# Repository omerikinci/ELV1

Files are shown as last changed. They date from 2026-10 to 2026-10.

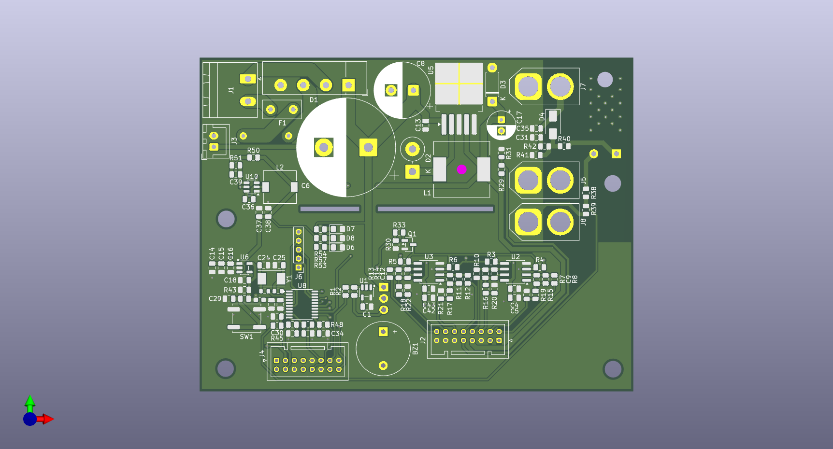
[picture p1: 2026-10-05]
hardware/Electronic Load no component.png

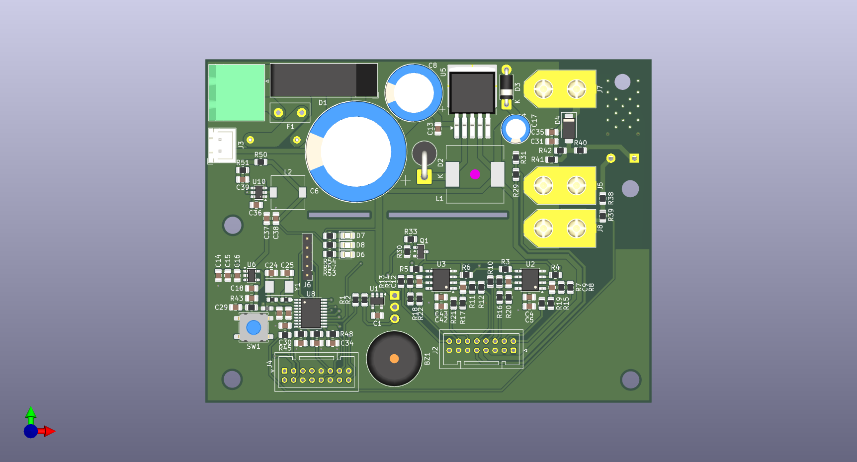
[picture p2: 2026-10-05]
hardware/Electronic Load.png

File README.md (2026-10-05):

# ELV1 — Elektronik Kör Yük V1

Elektronik kör yük (electronic dummy load) cihazının ilk stabil versiyonu.
150 W ile sınırlandırılmış, 30 V / 10 A aralığını destekler.

Proje detayları ve görseller: https://omerikinci.com/projects/electronic-dummy-load

## İçerik

| Klasör | Açıklama |
| --- | --- |
| `firmware/` | STM32G030F6 için STM32CubeIDE projesi (`ilkdeneme`). Final kod: `firmware/Core/Src/main.c` |
| `firmware-history/2026-04-27-stable/` | 27.04.2026 tarihli önceki stabil `main.c` |
| `hardware/` | KiCad şema ve PCB (`Electronic Load`), PCB görselleri, özel sembol kütüphanesi |
| `arduino-prototype/` | STM32'ye geçmeden önceki Arduino tabanlı ilk prototip (`koryukprojesi.ino`) |

## Firmware

- MCU: STM32G030F6Px
- ADS1115 (I2C) ile akım/gerilim ölçümü, dahili ADC
- DS18B20 sıcaklık sensörü
- I2C LCD, buzzer, soft-start

Derlemek için `firmware/` klasörünü STM32CubeIDE'ye mevcut proje olarak içe aktarın.

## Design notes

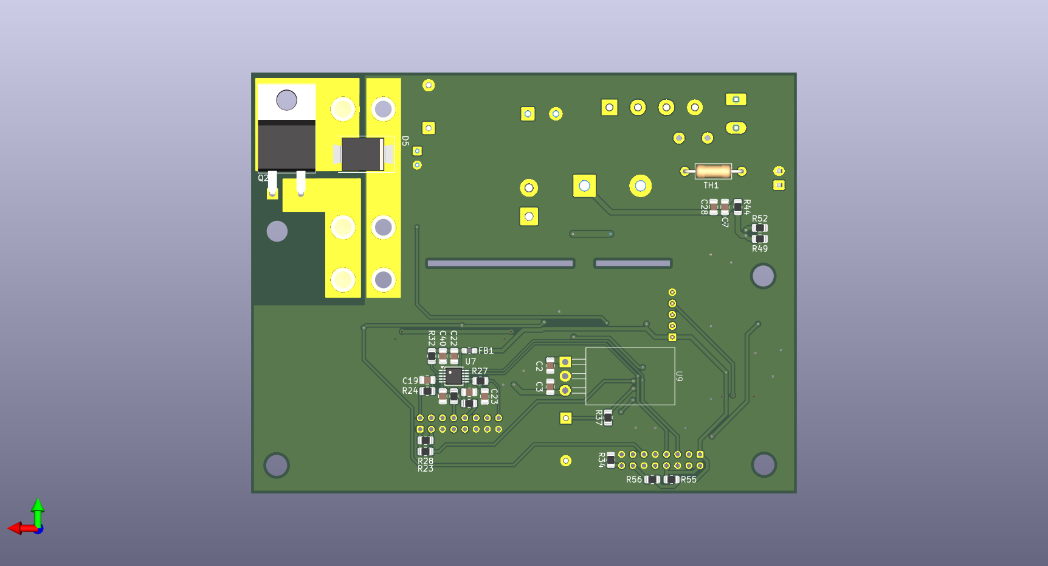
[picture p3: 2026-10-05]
hardware/Electronic Load back.png

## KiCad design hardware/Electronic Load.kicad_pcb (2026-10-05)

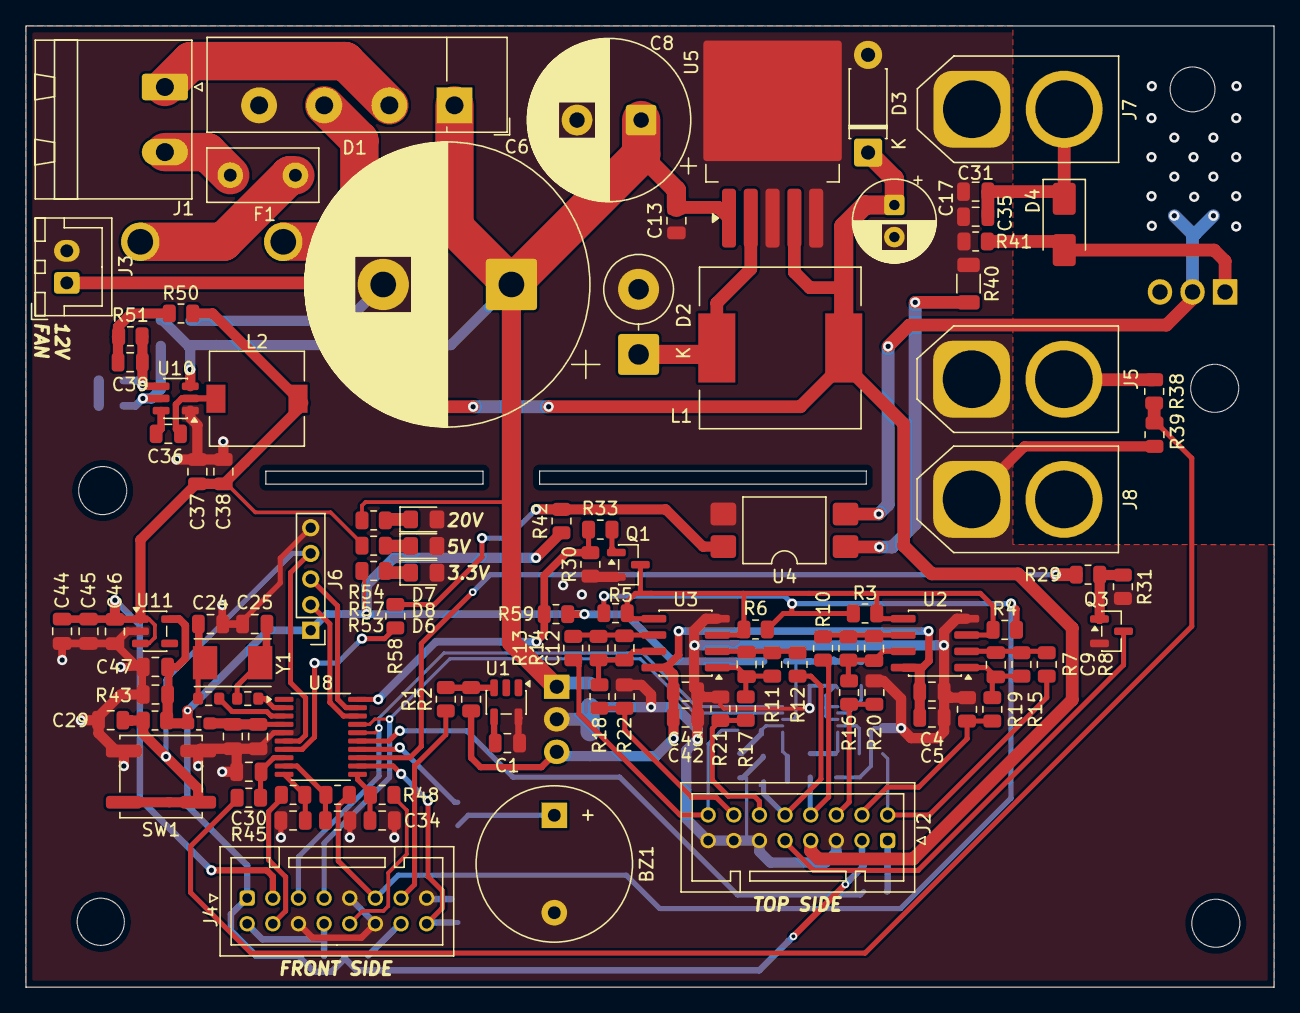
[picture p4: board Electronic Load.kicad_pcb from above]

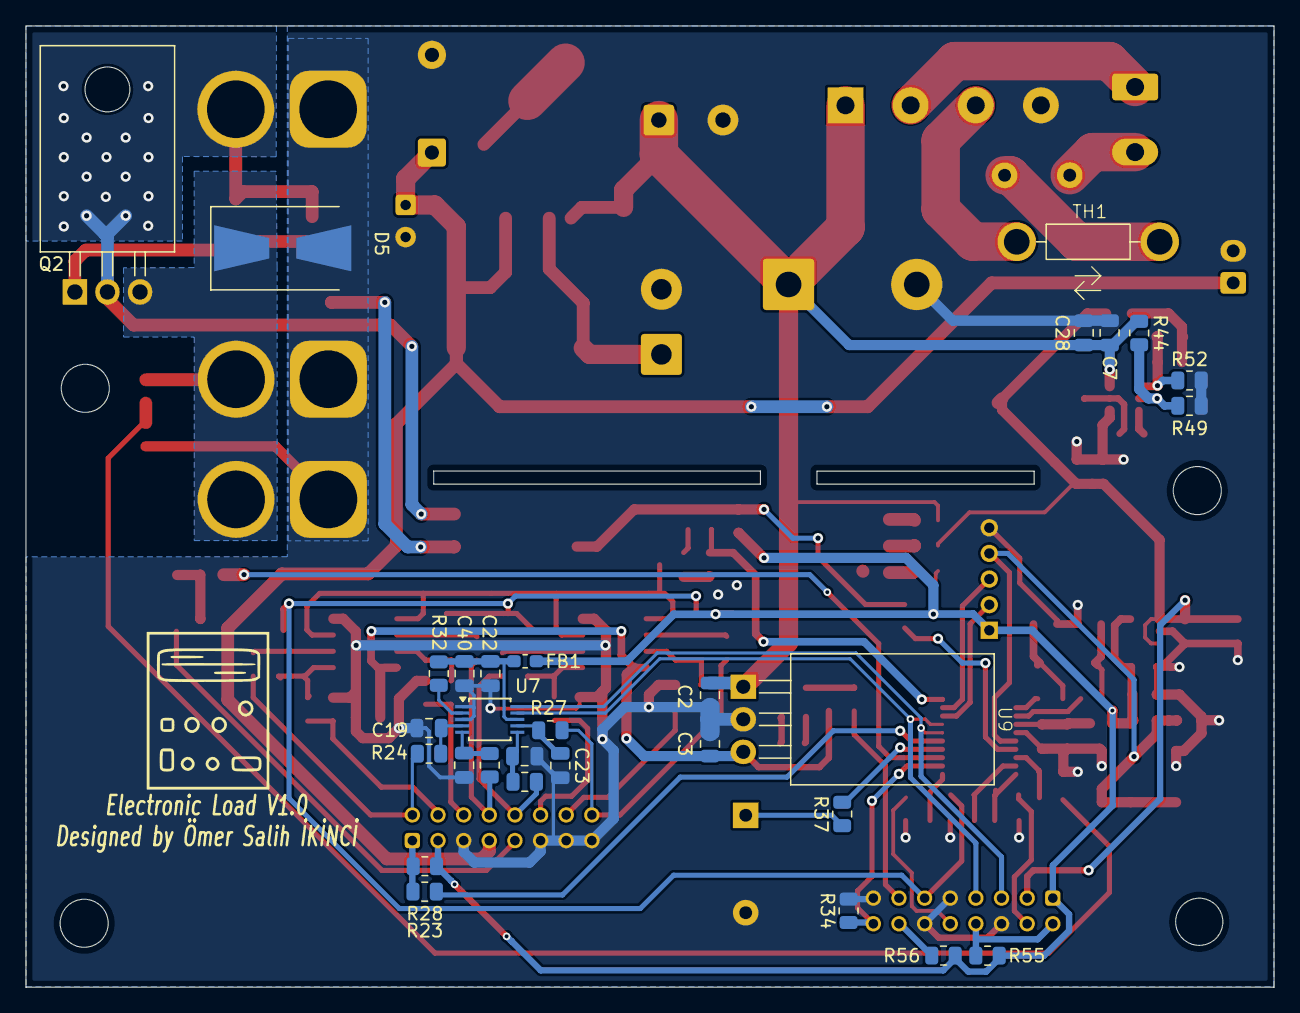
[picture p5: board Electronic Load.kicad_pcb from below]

Board: 2 copper layers, 97.3 x 75.0 mm, 140 parts (30 on the bottom side), 81 nets.

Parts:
BZ1: Buzzer; Buzzer_12x9.5RM7.6
C1, C26, C28, C40, C44: 10uF X7R; C_0805_2012Metric
C2, C3, C5, C7, C13, C19, C20, C21, C22, C23, C27, C29, C30, C32, C33, C34, C36, C42, C45, C48: 100nF X7R; C_0805_2012Metric
C4, C31, C43, C46, C47: 1uF X7R; C_0805_2012Metric
C6: 6800uF; CP_Radial_D22.0mm_P10.00mm_SnapIn
C8: 680uF 50V; CP_Radial_D12.5mm_P5.00mm
C9, C10, C11, C12: 1nF; C_0805_2012Metric
C17: 220uF 25V; CP_Radial_D6.3mm_P2.50mm
C24, C25: 18pF; C_0805_2012Metric
C35: 100nF 63V; C_0805_2012Metric
C37, C38: 22uF; C_0805_2012Metric
C39: 75pF; C_0805_2012Metric
D1: KBU8M; Diode_Bridge_Vishay_KBU
D2: 1N5822; D_DO-201AD_P5.08mm_Vertical_KathodeUp
D3: 1N4007; D_DO-41_SOD81_P7.62mm_Horizontal
D4: 12V ZENER; D_SMA
D5: SMCJ33CA-TKS; D_SMB-SMC_Universal_Handsoldering
D6, D7, D8: RED LED; LED_0805_2012Metric_Pad1.15x1.40mm_HandSolder
F1: 2A Slow Blow; Fuse_Littelfuse_395Series
FB1, FB2: 600R 100MHz; L_0603_1608Metric_Pad1.05x0.95mm_HandSolder
J1: 15VAC Transformer out; PhoenixContact_MSTBA_2,5_2-G-5,08_1x02_P5.08mm_Horizontal
J2: Top Panel; JST_PUD_B16B-PUDSS_2x08_P2.00mm_Vertical
J3: FAN OUT; JST_XH_B2B-XH-A_1x02_P2.50mm_Vertical
J4: Front Panel; JST_PUD_B16B-PUDSS_2x08_P2.00mm_Vertical
J5: power in (inside); AMASS_XT60-M_1x02_P7.20mm_Vertical
J6: Program Pins; PinHeader_1x05_P2.00mm_Vertical
J7: power in (outside); AMASS_XT60-M_1x02_P7.20mm_Vertical
J8: power in (outside) for batteries; AMASS_XT60-M_1x02_P7.20mm_Vertical
L1: 33uH; L_12x12mm_H8mm
L2: 10uH; L_7.3x7.3_H4.5
Q1, Q3: IRLML6344TRPBF; SOT-23
Q2: IRF4905; TO-220F-3_Horizontal_TabDown
R1: 22K; R_0805_2012Metric
R2, R19, R20, R21, R22, R30, R31, R32, R34, R42, R43, R59: 10K; R_0805_2012Metric
R3, R4, R5, R6, R8, R10, R12, R14, R24, R25, R26, R27, R41, R45, R46, R47, R48, R54, R55, R56: 1K; R_0805_2012Metric
R7, R9, R11, R13: 220K; R_0805_2012Metric
R15, R16, R17, R18, R23, R33, R37, R57: 100R; R_0805_2012Metric
R28: 4.7K; R_0805_2012Metric
R29, R58: 100; R_0805_2012Metric
R35, R36: 0R; R_0603_1608Metric
R38: 470K; R_0805_2012Metric
R39: 33K; R_0805_2012Metric
R40: 5.6K; R_1206_3216Metric
R44: 511K; R_0805_2012Metric
R49: 105K; R_0805_2012Metric
R50: 49.9R; R_0805_2012Metric
R51: 100K; R_0805_2012Metric
R52: 13.3K; R_0805_2012Metric
R53: 10R; R_0805_2012Metric
SW1: SW_Push_1P1T_NO_CK_KSC7xxJ
TH1: NTC 10R; Untitled
U1: TL431DBV; SOT-23-5
U2, U3: LM358; SOIC-8_3.9x4.9mm_P1.27mm
U4: LTV-817S; SMDIP-4_W9.53mm
U5: LM2596S-12; TO-263-5_TabPin3
U7: ADS1115IDGS; TSSOP-10_3x3mm_P0.5mm
U8: STM32G030F6Px; TSSOP-20_4.4x6.5mm_P0.65mm
U9: LM7815_TO220; myto220
U10: TPS54302; SOT-23-6
U11: AP2112K-3.3; SOT-23-5
Y1: 8mHz; Crystal_SMD_Abracon_ABM7-2Pin_6.0x3.5mm

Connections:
/3.3V: C47.1, C48.1, FB1.1, FB2.1, J2.3, J4.1, J6.1, R28.1, R42.2, R43.2, R53.2, R55.1, R56.1, R59.1, U11.5 (VOUT)
/5V: C37.1, C38.1, C44.1, C45.1, C46.1, J4.3, L2.2, R50.1, R57.2, U11.1 (VIN), U11.3 (EN)
/20V: C2.1, C6.1, C7.1, C8.1, C13.1, C28.1, D1.1 (+), R44.1, R54.2, U5.1 (VIN), U9.1 (VI), U10.3 (VIN)
/A POT SIGNAL: J4.11, R3.2, R4.2, R5.2, R6.2, R46.2
/A POT VCC: J4.13, R1.1
/ADS1115/SCREEN SCL: J4.5, U7.10 (SCL), U8.16 (PA9/PA11)
/ADS1115/SCREEN SDA: J4.7, U7.9 (SDA), U8.17 (PA10/PA12)
/AR0: J2.2, R8.1, R24.2
/AR1: J2.8, R10.1, R25.2
/AR2: J2.10, R12.1, R26.2
/AR3: J2.16, R14.1, R27.2
/BUZZER: R37.2, U8.14 (PA7)
/DRAIN SIDE: C31.1, C35.1, D4.1 (K), J7.2, Q2.2 (D), U4.2
/DS18B20 DQ: R23.2, U8.15 (PA8/PB0/PB1/PB2)
/FAN CONTROL: R29.2, U8.13 (PA6)
/FAN SIGNAL: J2.9, Q3.3 (D)
/FAN VCC: C17.1, D3.1 (K), J2.7, J3.1, L1.2, U5.4 (FB)
/G1: J2.4, R15.1, R19.1
/G2: J2.6, R16.1, R20.1
/G3: J2.12, R17.1, R21.1
/G4: J2.14, R18.1, R22.1
/LOAD VOLTAGE: R38.1, R39.2, R45.2
/OCS: Q1.3 (D), R3.1, R4.1, R5.1, R6.1, U2.3 (+), U2.5 (+), U3.3 (+), U3.5 (+)
/OPAMP CONTROL: R30.1, R33.1, R59.2, U8.20 (PB3/PB4/PB5/PB6)
/Opamp VCC: C3.1, C4.1, C5.1, C42.1, C43.1, R2.1, U2.8 (V+), U3.8 (V+), U9.3 (VO)
/RCP: R58.2, U8.7 (PA0)
/RESET BUTTON: J4.16, R34.1, U8.12 (PA5)
/SET C POT: J4.10, R48.2
/SET V POT: J4.4, R47.2
/SOURCE SIDE: D5.1 (A1), J5.2, J8.2, Q2.3 (S), R38.2
GND: BZ1.2 (-), C1.2, C2.2, C3.2, C4.2, C5.2, C6.2, C7.2, C8.2, C13.2, C17.2, C19.2, C20.2, C21.2, C22.2, C23.2, C24.1, C25.1, C26.2, C27.2, C28.2, C29.2, C30.2, C31.2, C32.2, C33.2, C34.2, C35.2, C37.2, C38.2, C40.2, C42.2, C43.2, C44.2, C45.2, C46.2, C47.2, C48.2, D1.4 (-), D2.2 (A), D3.2 (A), D5.2 (A2), D6.2 (A), D7.2 (A), D8.2 (A), J2.5, J2.11, J2.13, J2.15, J3.2, J4.6, J4.9, J4.12, J4.15, J5.1, J6.5, J7.1, J8.1, Q1.2 (S), Q3.2 (S), R19.2, R20.2, R21.2, R22.2, R30.2, R31.1, R34.2, R39.1, R40.1, R41.1, R49.2, R52.2, SW1.2, U1.5 (A), U2.4 (V-), U3.4 (V-), U4.3, U5.3 (GND), U5.5 (~ON/OFF), U7.1 (ADDR), U7.3 (GND), U8.5 (VSS), U9.2 (GND), U10.1 (GND), U11.2 (GND)
unnamed: BZ1.1 (+), R37.1
unnamed: C9.2, R7.1, R15.2, U2.1
unnamed: C10.2, R9.1, R16.2, U2.7
unnamed: C11.2, R11.1, R17.2, U3.1
unnamed: C12.2, R13.1, R18.2, U3.7
unnamed: C24.2, R35.1, Y1.2
unnamed: C25.2, R36.1, Y1.1
unnamed: C39.1, R50.2, R51.1
unnamed: D1.3, TH1.1
unnamed: D2.1 (K), L1.1, U5.2 (OUT)
unnamed: D4.2 (A), Q2.1 (G), R41.2
unnamed: D6.1 (K), R53.1
unnamed: D7.1 (K), R54.1
unnamed: D8.1 (K), R57.1
unnamed: F1.2, TH1.2
unnamed: D1.2, J1.1
unnamed: F1.1, J1.2
unnamed: J2.1, R23.1, R28.2
unnamed: J4.2, J4.8, R55.2
unnamed: J4.14, R56.2
unnamed: J6.2, U8.18 (PA13)
unnamed: J6.3, U8.19 (PA14/PA15)
unnamed: C29.1, J6.4, R43.1, SW1.1, U8.6 (NRST)
unnamed: Q1.1 (G), R33.2
unnamed: Q3.1 (G), R29.1, R31.2
unnamed: R40.2, U4.1
unnamed: R42.1, R58.1, U4.4
unnamed: R1.2, R2.2, U1.3 (K)
unnamed: C1.1, U1.4 (REF)
unnamed: C9.1, R7.2, R8.2, U2.2 (-)
unnamed: C10.1, R9.2, R10.2, U2.6 (-)
unnamed: C11.1, R11.2, R12.2, U3.2 (-)
unnamed: C12.1, R13.2, R14.2, U3.6 (-)
unnamed: C19.1, R24.1, U7.4 (AIN0)
unnamed: C20.1, R25.1, U7.5 (AIN1)
unnamed: C21.1, R26.1, U7.6 (AIN2)
unnamed: C23.1, R27.1, U7.7 (AIN3)
unnamed: R32.1, U7.2 (ALERT/RDY)
unnamed: C22.1, C40.1, FB1.2, R32.2, U7.8 (VDD)
unnamed: C30.1, R45.1, U8.8 (PA1)
unnamed: C32.1, R46.1, U8.9 (PA2)
unnamed: C33.1, R47.1, U8.10 (PA3)
unnamed: C34.1, R48.1, U8.11 (PA4)
unnamed: R36.2, U8.2 (PB9/PC14)
unnamed: R35.2, U8.3 (PC15)
unnamed: C26.1, C27.1, FB2.2, U8.4 (VDD)
unnamed: C36.1, U10.6 (BOOT)
unnamed: R44.2, R49.1, U10.5 (EN)
unnamed: C39.2, R51.2, R52.1, U10.4 (FB)
unnamed: C36.2, L2.1, U10.2 (SW)

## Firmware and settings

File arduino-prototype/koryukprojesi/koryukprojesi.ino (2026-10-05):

/*
 * Arduino Electronic Load Project (FINAL VERSION - 20x4 EDITION)
 * -----------------------------------------------------------
 * - OPTIMIZED FOR 20x4 DISPLAY (Professional Look) -
 * - ENGLISH INTERFACE FOR YOUTUBE / GLOBAL USE -
 * - HIGH VOLTAGE PROTECTION & MAX 20V SET LIMIT -
 * - FIXED: Display Flickering (Titreme) and Overwrite Issues -
 * - PREMIUM FEATURES: Fan Animation, Progress Bar, Haptic Sound -
 * -----------------------------------------------------------
 * * * PIN CONNECTIONS:
 * A0: Current Sense (1V = 1A)
 * A1: Voltage Sense (Max 50V)
 * A2: Set Current Pot (Max 5A)
 * A3: Set Voltage Pot (Max 20V)
 * D8: Load Control MOSFET (Safety Cutoff - HIGH triggers OFF)
 * D2: Reset Button (Active LOW)
 * D5: Buzzer
 * D9: DS18B20 One-Wire Bus
 * D11: Fan MOSFET (Low-Side Switching)
 * SDA/SCL: 20x4 I2C LCD Display
 */

#include <Wire.h>
#include <LiquidCrystal_I2C.h>
#include <OneWire.h>
#include <DallasTemperature.h>

// --- LCD Settings (UPDATED FOR 20x4) ---
LiquidCrystal_I2C lcd(0x27, 20, 4);  // 20 Columns, 4 Rows

// --- Pin Definitions ---
const int CURRENT_PIN = A0;
const int VOLTAGE_PIN = A1;
const int SET_CURRENT_PIN = A2;
const int SET_VOLTAGE_PIN = A3;
const int INDICATOR_POT_PIN = A7;

const int RESET_BUTTON_PIN = 2;
const int BUZZER_PIN = 5;
const int LOAD_CONTROL_PIN = 8;    // D8 - Safety Cutoff MOSFET
const int ONE_WIRE_BUS_PIN = 9;    // D9 - DS18B20 Sensors
const int FAN_MOSFET_PIN = 11;     // D11 - Fan MOSFET

// --- Control Logic ---
const int LOAD_ON = LOW;       // Normal Operation (D8 LOW)
const int LOAD_OFF = HIGH;     // Fault State (D8 HIGH)
const int FAN_ON = HIGH;
const int FAN_OFF = LOW;

// --- Calibration & Settings ---
const float V_REF = 5.0;  
const float VOLTAGE_DIVIDER_RATIO = 11.0;  
const float MIN_CURRENT_THRESHOLD = 0.05;  

// --- Thermal Control Settings ---
const float FAN_ON_TEMP_THRESHOLD = 55.0;
const float FAN_OFF_TEMP_THRESHOLD = 45.0;
const float TEMP_FAULT_LIMIT = 65.0;  

// --- PROTECTION LIMITS ---
const float HIGH_VOLTAGE_PROTECTION = 21.0;  

// --- Global Variables ---
float actualVoltage = 0.0;
float actualCurrent = 0.0;
float setVoltage = 0.0;
float setCurrent = 0.0;
float power = 0.0;
int indicatorPotValue = 0;

bool faultState = false;
String faultMessage = "";

// --- Temp & Fan Variables ---
OneWire oneWire(ONE_WIRE_BUS_PIN);
DallasTemperature sensors(&oneWire);
float tempS2 = 0.0; // S2 (MOSFET Temp)
float tempS1 = 0.0; // S1 (Resistor Temp)
bool isFanOn = false;

// Sabit etiketleri sadece bir kez yazdırmak için bayraklar
bool labelsPrinted = false;

// --- Timing Variables for Async Temp Reading ---
unsigned long lastTempUpdate = 0;
const unsigned long TEMP_UPDATE_INTERVAL = 1000; // 1 saniyede bir sıcaklık oku

// --- Custom Characters & Animation ---
byte charFan1[8] = {0x04,0x0E,0x1F,0x04,0x1F,0x0E,0x04,0x00}; // Pervane +
byte charFan2[8] = {0x1B,0x0E,0x04,0x0E,0x1B,0x00,0x00,0x00}; // Pervane x
byte charBar[8]  = {0xFF,0xFF,0xFF,0xFF,0xFF,0xFF,0xFF,0xFF}; // Full Block

unsigned long lastFanAnimTime = 0;
const int FAN_ANIM_DELAY = 250; // 250ms de bir yön değişir
int fanFrame = 0; // 0 veya 1


void setup() {
  Serial.begin(9600);

  // Set Pin Modes
  pinMode(LOAD_CONTROL_PIN, OUTPUT);
  pinMode(RESET_BUTTON_PIN, INPUT);
  pinMode(BUZZER_PIN, OUTPUT);
  pinMode(FAN_MOSFET_PIN, OUTPUT);
  
  // Initial States
  digitalWrite(LOAD_CONTROL_PIN, LOAD_ON);    // Load ON
  digitalWrite(BUZZER_PIN, LOW);             // Buzzer OFF
  digitalWrite(FAN_MOSFET_PIN, FAN_OFF);     // Fan OFF
  
  // Init LCD
  lcd.init();
  lcd.backlight();
  lcd.clear();
  
  // Create Custom Characters
  lcd.createChar(0, charFan1);
  lcd.createChar(1, charFan2);
  lcd.createChar(2, charBar); // Progress Bar Block

  // --- SHOW LOADING SCREEN ---
  lcd.setCursor(2, 1);
  lcd.print("SYSTEM STARTING");
  
  // Progress Bar Animation (20 Karakterlik Çubuk)
  lcd.setCursor(0, 2);
  for (int i = 0; i < 20; i++) {
    lcd.write(2); // Block karakterini yaz
    delay(75);    // Hız ayarı (Toplam ~1.5sn sürer)
  }
  
  lcd.clear();
  
  // --- WELCOME SCREEN (Short) ---
  lcd.setCursor(2, 0);  
  lcd.print("ELECTRONIC LOAD");
  lcd.setCursor(4, 1);
  lcd.print("Version 2.0"); // V2.0 PRO
  delay(1500);
  
  // Init Sensors
  sensors.begin();
  
  // ASYNC MODE: İşlemciyi bekletme
  sensors.setWaitForConversion(false); 
  sensors.requestTemperatures(); // İlk çevrimi başlat
  
  delay(100); 

  faultState = false;
  lcd.clear();
  // İlk çalıştırmada sabit etiketleri yazdır
  printFixedLabels(); 
}

/**
 * @brief Ekrana sabit etiketleri (Set:, Act:, Pwr:, Mos:, Res:, Pot:) sadece bir kez yazar.
 * Bu, ana döngüde (loop) tekrarlanan yazımı ve titremeyi önler.
 */
void printFixedLabels() {
  // Line 1: Set Values Labels
  lcd.setCursor(0, 0);
  lcd.print("Set: ");
  // Line 2: Actual Values Labels
  lcd.setCursor(0, 1);
  lcd.print("Act: ");
  // Line 3: Power & Pot Labels
  lcd.setCursor(0, 2);
  lcd.print("Pwr: "); // POWER -> PWR KISALTILDI
  lcd.setCursor(11, 2); // POT Sola hizalandı
  lcd.print("Pot:"); 
  // Line 4: Temps Labels
  lcd.setCursor(0, 3);
  lcd.print("Mos:");
  lcd.setCursor(8, 3); // Res Sola hizalandı
  lcd.print("Res:");
  
  labelsPrinted = true;
}


void loop() {
  
  // 1. Check Reset Button
  if (faultState == true) {
    if (digitalRead(RESET_BUTTON_PIN) == LOW) {  
      delay(50); // Debounce
      if (digitalRead(RESET_BUTTON_PIN) == LOW) {
        // Reset Faults
        tone(BUZZER_PIN, 2000, 100); // Bip sesi ile onay
        faultState = false;
        faultMessage = "";
        digitalWrite(LOAD_CONTROL_PIN, LOAD_ON);  
        digitalWrite(BUZZER_PIN, LOW);            
        lcd.clear();
        lcd.setCursor(3, 1);
        lcd.print("SYSTEM ACTIVE");
        delay(1000);
        lcd.clear();
        // Reset sonrası sabit etiketleri yeniden yazdır
        printFixedLabels(); 
        return;
      }
    }
  }

  // 2. Read Sensors
  readSensors();
  readTemperatures();

  // 3. Fan Control
  controlFan();

  // 4. Fault Check
  if (faultState == false) {
    
    // *** HIGH VOLTAGE PROTECTION (>21V) ***
    if (actualVoltage > HIGH_VOLTAGE_PROTECTION) {  
      setFault("FAULT: HIGH VOLTAGE");
    }
    // Over Current
    else if (actualCurrent > setCurrent) {
      setFault("FAULT: OVER CURRENT");
    }  
    // Low Voltage
    else if (actualVoltage < setVoltage && actualCurrent > MIN_CURRENT_THRESHOLD) {
      setFault("FAULT: LOW VOLTAGE");
    }
    // Over Temp
    else if (tempS1 > TEMP_FAULT_LIMIT || tempS2 > TEMP_FAULT_LIMIT) {
      setFault("FAULT: OVER HEATING");
    }
  }

  // 5. Update Display
  if (faultState) {
    displayFault();
  } else {
    // Sabit etiketler (Set:, Act:, Pwr: vb.) zaten yazıldıysa, sadece dinamik değerleri güncelle
    updateDynamicValues();
  }
}

/**
 * @brief Triggers a system fault.
 */
void setFault(String message) {
  faultState = true;
  faultMessage = message;
  
  digitalWrite(LOAD_CONTROL_PIN, LOAD_OFF); // Cut Power
  digitalWrite(BUZZER_PIN, HIGH);
  lcd.clear(); // Hata durumunda ekranı temizle (Mos vb. kalmasın)
}

/**
 * @brief Reads all analog inputs.
 */
void readSensors() {
  // Set Current (Max 5A)
  int setAmperRaw = analogRead(SET_CURRENT_PIN);
  setCurrent = map(setAmperRaw, 0, 1023, 0, 500) / 100.0;

  // Set Voltage (Max 20V Limit)
  int setVoltajRaw = analogRead(SET_VOLTAGE_PIN);
  setVoltage = map(setVoltajRaw, 0, 1023, 0, 2000) / 100.0;  

  // Actual Current
  int actualCurrentRaw = analogRead(CURRENT_PIN);
  float actualCurrentVolts = (actualCurrentRaw / 1023.0) * V_REF;
  actualCurrent = actualCurrentVolts;  

  // Actual Voltage
  int actualVoltajRaw = analogRead(VOLTAGE_PIN);
  float pinVoltage = (actualVoltajRaw / 1023.0) * V_REF;
  actualVoltage = pinVoltage * VOLTAGE_DIVIDER_RATIO;
  
  power = actualVoltage * actualCurrent;
  indicatorPotValue = analogRead(INDICATOR_POT_PIN);
}

void readTemperatures() {
  // Sadece 1 saniyede bir işlem yap (Non-blocking)
  if (millis() - lastTempUpdate >= TEMP_UPDATE_INTERVAL) {
    lastTempUpdate = millis();
    
    // 1. Sensörde HAZIR olan değeri oku (Bir önceki istekten gelen)
    float temp1 = sensors.getTempCByIndex(1);
    float temp0 = sensors.getTempCByIndex(0);

    if (temp0 != DEVICE_DISCONNECTED_C && temp0 > -127.0) {
      tempS2 = temp0; // Index 0 -> S2 (Resistor)
    }
    if (temp1 != DEVICE_DISCONNECTED_C && temp1 > -127.0) {
      tempS1 = temp1; // Index 1 -> S1 (MOSFET)
    }
    
    // 2. Bir SONRAKİ okuma için sensöre "Çevrime Başla" emri ver
    // WaitForConversion(false) olduğu için işlemciyi bekletmez, hemen döner.
    sensors.requestTemperatures();
  }
}

/**
 * @brief Controls Fan based on temp.
 */
void controlFan() {
  if (tempS1 > FAN_ON_TEMP_THRESHOLD || tempS2 > FAN_ON_TEMP_THRESHOLD) {
    isFanOn = true;
  }  
  else if (tempS1 < FAN_OFF_TEMP_THRESHOLD && tempS2 < FAN_OFF_TEMP_THRESHOLD) {
    isFanOn = false;
  }
  
  if (isFanOn) {
    digitalWrite(FAN_MOSFET_PIN, FAN_ON);  
  } else {
    digitalWrite(FAN_MOSFET_PIN, FAN_OFF);  
  }
}

/**
 * @brief Sadece dinamik değerleri günceller, sabit etiketlere dokunmaz. (20x4 Optimized)
 */
void updateDynamicValues() {
  // Line 1: Set Values
  // Başlangıç: Kolon 5 (Set: 01234)
  lcd.setCursor(5, 0); 
  lcd.print(String(setVoltage, 1));
  lcd.print("V "); // Sabit uzunluk koruma (Tek boşluk)
  // Başlangıç: Kolon 11
  lcd.setCursor(11, 0); 
  lcd.print(String(setCurrent, 2));
  lcd.print("A "); // Sabit uzunluk koruma (Tek boşluk)

  // Line 2: Actual Values
  // Başlangıç: Kolon 5 (Act: 01234)
  lcd.setCursor(5, 1);
  lcd.print(String(actualVoltage, 1));
  lcd.print("V "); // Sabit uzunluk koruma
  // Başlangıç: Kolon 11
  lcd.setCursor(11, 1);
  lcd.print(String(actualCurrent, 2));
  lcd.print("A "); // Sabit uzunluk koruma

  // Line 3: Power & Pot
  // Başlangıç: Kolon 5 (Pwr: 01234)
  lcd.setCursor(5, 2);
  lcd.print(String(power, 1));
  lcd.print("W "); // Sabit uzunluk koruma - Tek boşluk (P harfini korur)
  
  // Pot değerini güncelle. Başlangıç: Kolon 15 (Pot: 12345)
  lcd.setCursor(15, 2); 
  lcd.print(indicatorPotValue);
  
  // Taşmayı önlemek için akıllı boşluk (Toplam 5 karakter alanı: 15-19)
  if (indicatorPotValue < 10) lcd.print("    ");      // 1 rakam + 4 boşluk
  else if (indicatorPotValue < 100) lcd.print("   "); // 2 rakam + 3 boşluk
  else if (indicatorPotValue < 1000) lcd.print("  "); // 3 rakam + 2 boşluk
  else lcd.print(" ");                                // 4 rakam + 1 boşluk

  // Line 4: Temps & Fan Status
  // Mos Temp. Başlangıç: Kolon 4 (Mos: 0123)
  lcd.setCursor(4, 3);
  lcd.print(String((int)tempS1)); 
  lcd.print("C "); // Sabit uzunluk koruma
  
  // Res Temp. Başlangıç: Kolon 12 (Res: 8901)
  lcd.setCursor(12, 3);
  lcd.print(String((int)tempS2));
  lcd.print("C ");
  
  // Fan Status. Başlangıç: Kolon 16
  lcd.setCursor(16, 3);
  if (isFanOn) {
    // Animasyon Mantığı
    if (millis() - lastFanAnimTime >= FAN_ANIM_DELAY) {
      lastFanAnimTime = millis();
      fanFrame = !fanFrame; // 0 -> 1, 1 -> 0 Geçiş
    }
    
    lcd.print("FAN");
    lcd.write(fanFrame); // 0 veya 1 nolu karakteri bas
  } else {
    lcd.print("    "); // Temizle
  }
}

/**
 * @brief Displays Fault Screen (Centered)
 */
void displayFault() {
  // Line 0: Header (Centered)
  // "SYSTEM HALTED!" is 14 chars. (20-14)/2 = 3
  lcd.setCursor(3, 0);
  lcd.print("SYSTEM HALTED!");

  // Line 1: Error Message (Dynamic)
  lcd.setCursor(0, 1);
  lcd.print(faultMessage); // e.g. "FAULT: HIGH VOLTAGE"
  // Clear rest of line
  for (int i = faultMessage.length(); i < 20; i++) {
    lcd.print(" ");
  }

  // Line 2: Frozen Values
  lcd.setCursor(1, 2); // Indent slightly
  lcd.print("V:");
  lcd.print(String(actualVoltage, 1));
  lcd.print("  A:");
  lcd.print(String(actualCurrent, 2));
  lcd.print("    ");

  // Line 3: Instruction
  // "Press Reset..." is 14 chars.
  lcd.setCursor(3, 3);
  lcd.print("Press Reset...");
}

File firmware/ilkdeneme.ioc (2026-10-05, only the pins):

Mcu.UserName=STM32G030F6Px
PA0.Signal=ADC1_IN0
PA1.Signal=ADC1_IN1
PA13.Signal=SYS_SWDIO
PA14-BOOT0.Signal=SYS_SWCLK
PA2.Signal=ADC1_IN2
PA3.Signal=ADC1_IN3
PA4.Signal=SharedAnalog_PA4
PA5.Signal=ADC1_IN5
PA6.Signal=GPIO_Output
PA7.Signal=GPIO_Output
PB0.Signal=GPIO_Output
PB3.Signal=GPIO_Output
PB7.Signal=ADC1_IN11

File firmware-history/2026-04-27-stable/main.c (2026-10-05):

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
/* Includes ------------------------------------------------------------------*/
#include "main.h"

/* USER CODE BEGIN Includes */
#include <stdio.h>
/* USER CODE END Includes */

ADC_HandleTypeDef hadc1;

I2C_HandleTypeDef hi2c2;

void SystemClock_Config(void);
static void MX_GPIO_Init(void);
static void MX_ADC1_Init(void);
static void MX_I2C2_Init(void);
/* USER CODE BEGIN PFP */
static uint8_t adc_read_channel(uint32_t channel, uint16_t *raw_value);
static uint8_t adc_read_channel_avg(uint32_t channel, uint8_t samples, uint16_t *raw_avg);
static uint32_t adc_raw_to_millivolt(uint16_t raw);
static uint32_t lv_adc_to_input_millivolt(uint16_t raw);
static void delay_us_init(void);
static void delay_us(uint32_t us);
static uint8_t ds18b20_crc8(const uint8_t *data, uint8_t len);
static uint8_t ds18b20_start_conversion(void);
static uint8_t ds18b20_read_temp_centi(int16_t *temp_centi);
static uint8_t ads1115_detect_address(void);
static uint8_t ads1115_read_channel_raw_cfg(uint8_t channel, uint16_t pga_cfg, int16_t *raw_value);
static uint8_t ads1115_read_avg_microvolt_cfg(uint8_t channel, uint16_t pga_cfg, int32_t fs_uv, uint32_t *avg_uv);
static uint8_t ads1115_read_avg_microvolt(uint32_t *avg_uv);
static uint8_t lcd_detect_address(void);
static void lcd_init(void);
static void lcd_set_cursor(uint8_t row, uint8_t col);
static void lcd_print(const char *text);
static void lcd_print_centered(uint8_t row, const char *text);
static void lcd_startup_loading_until_ds_ready(void);
static void shdn_softstart(void);
static void buzzer_tone(uint16_t freq_hz, uint16_t duration_ms, uint16_t duty_permille);
static void buzzer_pattern_startup(void);
static void buzzer_pattern_halt(void);
static void buzzer_pattern_system_on(void);
static void buzzer_pattern_system_off(void);
/* USER CODE END PFP */

/* USER CODE BEGIN 0 */
#define LCD_RS_BIT        0x01U
#define LCD_EN_BIT        0x04U
#define LCD_BL_BIT        0x08U
#define LCD_CMD_MODE      0x00U
#define LCD_DATA_MODE     LCD_RS_BIT
#define LCD_I2C_TIMEOUT   5U
#define LCD_DEFAULT_ADDR  (0x27U << 1)
#define ADC_VREF_MV       3300UL
#define ADC_MAX           4095UL
#define LV_DIV_TOP_OHM    47000UL
#define LV_DIV_BOT_OHM    3300UL
#define LV_OFFSET_MV      1500UL
#define LV_PROTECT_MV     30000UL
#define RV_REVERSE_TRIP_MV 3100UL
#define RESET_ADC_TRIP_MV 1500UL
#define ADS1115_DEFAULT_ADDR (0x48U << 1)
#define ADS1115_REG_CONV     0x00U
#define ADS1115_REG_CONFIG   0x01U
#define ADS1115_CFG_OS_SINGLE      0x8000U
#define ADS1115_CFG_PGA_512MV      0x0800U
#define ADS1115_CFG_MODE_SINGLE    0x0100U
#define ADS1115_CFG_DR_128SPS      0x0080U
#define ADS1115_CFG_COMP_DISABLE   0x0003U
#define ADS1115_FS_UV_CURRENT      512000L
#define ADS1115_SAMPLES_PER_CH     8U
#define CURRENT_ADS_CHANNEL        0U
#define CURRENT_UV_PER_A           29586UL
#define CURRENT_TRIP_MA            10000UL
#define POWER_TRIP_MW              160000UL
#define OCP_CONFIRM_COUNT          3U
#define POWER_CONFIRM_COUNT        3U
#define POWER_CHECK_DELAY_MS       500UL
#define PROT_PRESENT_THRESHOLD_MV  2500UL
#define UNPROT_PRESENT_THRESHOLD_MV 2000UL
#define PROT_MIN_MV                8000UL
#define SET_V_MAX_MV               30000UL
#define SET_A_MAX_MA               10000UL
#define SET_V_ZERO_DEADBAND_MV     1000UL
#define SET_A_ZERO_DEADBAND_MA     350UL
#define ISET_SCALED_MIN            30UL
#define ISET_SCALED_MAX            118UL
#define ISET_MAX_PERCENT           100UL
#define ISET_ZERO_DEADBAND_PERCENT 1UL
#define DS_GPIO_Port      GPIOB
#define DS_Pin            GPIO_PIN_0
#define FAN_GPIO_Port     GPIOA
#define FAN_Pin           GPIO_PIN_6
#define BUZZER_GPIO_Port  GPIOA
#define BUZZER_Pin        GPIO_PIN_7
#define BUZZER_DUTY_PERMILLE  140U
#define TEMP_FAN_ON_CENTI 5000
#define TEMP_FAN_OFF_CENTI 4000
#define DS18B20_CONV_WAIT_MS 850UL
#define DS18B20_RETRY_COUNT  3U
#define DS18B20_FAIL_FILTER  3U
#define TEMP_TRIP_CENTI   9000
#define SHDN_GPIO_Port    GPIOB
#define SHDN_Pin          GPIO_PIN_3
#define SHDN_SOFTSTART_ENABLE      1U
#define SHDN_SOFTSTART_STEPS       60U
#define SHDN_SOFTSTART_PERIOD_US   2000U
#define SHDN_SOFTSTART_PRIME_US    500U
#define RST_BTN_GPIO_Port GPIOA
#define RST_BTN_Pin       GPIO_PIN_5
#define PROTECT_NONE      0U
#define PROTECT_LV_OV     1U
#define PROTECT_REVERSE   2U
#define PROTECT_TEMP      3U
#define PROTECT_OC        4U
#define PROTECT_LOW_V     5U
#define PROTECT_POWER     6U

static uint8_t lcd_addr = LCD_DEFAULT_ADDR;
static uint8_t ads_addr = ADS1115_DEFAULT_ADDR;
static uint8_t us_timer_ready = 0U;

static uint32_t irq_save(void)
{
  uint32_t primask = __get_PRIMASK();
  __disable_irq();
  return primask;
}

static void irq_restore(uint32_t primask)
{
  if (primask == 0U)
  {
    __enable_irq();
  }
}

static void delay_us_init(void)
{
  if (us_timer_ready != 0U)
  {
    return;
  }

  RCC->APBENR2 |= RCC_APBENR2_TIM16EN;
  TIM16->CR1 = 0U;
  TIM16->PSC = (uint16_t)((SystemCoreClock / 1000000U) - 1U);
  TIM16->ARR = 0xFFFFU;
  TIM16->EGR = TIM_EGR_UG;
  TIM16->CNT = 0U;
  TIM16->CR1 = TIM_CR1_CEN;
  us_timer_ready = 1U;
}

static void delay_us(uint32_t us)
{
  uint16_t start;

  if (us == 0U)
  {
    return;
  }

  if (us_timer_ready == 0U)
  {
    delay_us_init();
  }

  start = (uint16_t)TIM16->CNT;
  while ((uint16_t)(TIM16->CNT - start) < (uint16_t)us)
  {
  }
}

static void onewire_drive_low(void)
{
  HAL_GPIO_WritePin(DS_GPIO_Port, DS_Pin, GPIO_PIN_RESET);
}

static void onewire_release(void)
{
  HAL_GPIO_WritePin(DS_GPIO_Port, DS_Pin, GPIO_PIN_SET);
}

static uint8_t onewire_read_pin(void)
{
  return (HAL_GPIO_ReadPin(DS_GPIO_Port, DS_Pin) == GPIO_PIN_SET) ? 1U : 0U;
}

static uint8_t onewire_reset_pulse(void)
{
  uint32_t irq_state;
  uint8_t presence_low;
  uint8_t line_recovered_high;

  onewire_release();
  delay_us(5U);
  if (onewire_read_pin() == 0U)
  {
    return 0U;
  }

  irq_state = irq_save();
  onewire_drive_low();
  delay_us(500U);
  onewire_release();
  delay_us(70U);
  presence_low = (onewire_read_pin() == 0U) ? 1U : 0U;
  delay_us(430U);
  line_recovered_high = (onewire_read_pin() != 0U) ? 1U : 0U;
  irq_restore(irq_state);

  return (uint8_t)((presence_low != 0U) && (line_recovered_high != 0U));
}

static void onewire_write_bit(uint8_t bit)
{
  uint32_t irq_state = irq_save();
  onewire_drive_low();
  if (bit != 0U)
  {
    delay_us(6U);
    onewire_release();
    delay_us(64U);
  }
  else
  {
    delay_us(60U);
    onewire_release();
    delay_us(10U);
  }
  irq_restore(irq_state);
}

static uint8_t onewire_read_bit(void)
{
  uint32_t irq_state = irq_save();
  uint8_t bit;

  onewire_drive_low();
  delay_us(6U);
  onewire_release();
  delay_us(9U);
  bit = onewire_read_pin();
  delay_us(55U);
  irq_restore(irq_state);
  return bit;
}

static void onewire_write_byte(uint8_t data)
{
  uint8_t i;
  for (i = 0U; i < 8U; i++)
  {
    onewire_write_bit((uint8_t)(data & 0x01U));
    data >>= 1;
  }
}
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

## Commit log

2026-10-05 ELV1: firmware, KiCad hardware and Arduino prototype
    [Electronic Load.kicad_pcb, Electronic Load.kicad_sch, untitled.kicad_sch]
2026-10-11 Reorganize hardware: rename Electronic Load to ELV1, add ELV1-revision and KiCad libraries
    - Move the KiCad project into hardware/ELV1/ and rename its files from 'Electronic Load' to 'ELV1'
    - Add the ELV1 revision board as hardware/ELV1-revision/
    - Add custom symbol and footprint libraries under hardware/libraries/
    - Update library references to the renamed libraries (my-NMOS -> myNMOS, myNTC:Untitled -> myNTC:NTC)
    - Ignore KiCad backup and local state files
2026-10-17 firmware: fix voltage measurement and lower V-drop current threshold
    - Lower SET_V_LOW_MIN_CURRENT_MA from 100 mA to 10 mA so the voltage
    collapse protection also trips during low-current tests.
    - Run HAL_ADCEx_Calibration_Start() at startup; the datasheet accuracy
    figures only apply after calibration and none was being done.
    - Measure the real VDDA through VREFINT and its factory calibration value
    instead of assuming a fixed 3300 mV (falls back to 3300 mV if the
    result is outside 2.9-3.6 V).
    - Sample the voltage dividers and VREFINT with 160.5 cycles (5 us):
    VREFINT needs >= 4 us and the ~31 kOhm unprotected divider has no
    capacitor at the ADC pin.
    - Round instead of truncating: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
2026-10-17 firmware: revert ADC calibration/VREFINT changes, keep threshold and rounding
    Testing on the board showed the voltage reading 1-1.8 V off and ISET
    stuck at 0 after 9eba3c0. The existing empirical constants
    (LV_OFFSET_MV = 1500, ISET_SCALED_MIN/MAX, the zero dead bands) were
    tuned on the uncalibrated ADC, so enabling HAL_ADCEx_Calibration_Start()
    shifted every reading against them.
    This restores the ADC path to the f1d0f2d behaviour:
    - no ADC calibration, no VREFINT/VDDA measurement (fixed 3300 mV),
    - original sampling time (79.5 cycles) on all channels.
    Kept from 9eba3c0:
    - SET_V_LOW_MIN_CURRENT_MA = 10 mA (confirmed working on the board),
    - rounding in ADC averaging and mV conversion,
    - r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
2026-10-18 hardware: sync ELV1 revision (G071 design) and libraries for multi-machine work
    - Replace the 11.10 ELV1-revision snapshot with the current KiCad project
    ("ELV1 revision": STM32G071CBT6, second ADS1115, 20V SENSE, I2C pull-ups,
    piezo buzzer fixes, castellated TO-247 edge footprint). File names keep
    the original project name so symbol instance data stays valid.
    - Add project-local sym-lib-table / fp-lib-table pointing to
    ${KIPRJMOD}/../libraries so the project opens on another machine
    (e.g. macOS) without global library setup.
    - Update hardware/libraries with the latest footprints
    (TO-247 Edge Castellated, Başlıksız).
    - Add the G071 pin plan and the firmware guide next to the p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
2026-10-18 hardware: kütüphaneleri global'e al, pin planındaki eskimiş notları düzelt
    Kütüphaneler:
    - Proje-içi sym-lib-table / fp-lib-table kaldırıldı (ELV1-revision ve ELV1).
    Global tabloda aynı isimler tanımlıyken KiCad çakışma uyarısı veriyordu.
    Kütüphaneler global olduğu için proje artık konumdan bağımsız; KiCad
    dosyalarında göreli kütüphane yolu kalmadı.
    - Kanonik adlar ELV1 revision'ın adlandırması: my-NMOS -> myNMOS,
    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
2026-10-18 ELV1 revision guide: pin-compatible backup MCUs for STM32G071CBT6
2026-10-18 ELV1 revision guide: STM32G071CBT6 supply sources (Farnell TR, Mouser TR)
2026-10-18 ELV1 revision guide: J4 20-pin connector sourcing (KLS out of stock, JST PHD alternative)
2026-10-18 ELV1 revision: J4 footprint JST PUD -> JST PHD (B20B-PHDSS), same pad grid
2026-10-18 Revert J4 footprint change (connector stays KLS PHB 2.0); note ELV1 temporary X-cap bleeder
    This reverts commit 97f4282.
2026-10-19 firmware: ELV1 with 2 MOSFETs (U1+U6), sum AIN0+AIN1 single-ended
    - Read only populated shunt channels (CURRENT_ADS_CH_MASK) and sum them
    - PGA +/-1.024 V (5 A x 0.1R per channel exceeds 512 mV), 250 SPS
    - CURRENT_UV_PER_A 109172 derived from old 4-MOSFET calibration
2026-10-19 firmware: fix ADS1115 PGA bits for +/-1.024 V (0x0600, was 0x0400 = 2.048 V)
    Current read exactly half of actual.
2026-10-20 ELV1 revision guide: H18 shunt heating (0.1R 2512 at 5 A = 2.5 W), 2x0.2R parallel proposal
2026-10-20 firmware: ELV1 shunts 2x0.1R parallel (0.05R per channel), PGA back to +/-0.512 V
    CURRENT_UV_PER_A 59172 (0.05 + 2 x Rg 4.59 mOhm). Hardware: 2 MOSFETs (U1, U6),
    OPA2197; repo schematic intentionally left as the original 4-MOSFET/LM358 design.
2026-10-20 README: ELV1 final state and deviations from schematic
2026-10-20 ELV1 revision: H18 - R116/R117 VMS-R100 parallel to R18/R19 (0.05R per channel), R2 22k
    Setpoint full scale stays ~12 A total; ADS #1 PGA moves to +/-0.512 V.
    Firmware guide and pin plan updated.
